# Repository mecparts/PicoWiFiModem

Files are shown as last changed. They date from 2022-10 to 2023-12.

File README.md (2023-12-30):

# Pico WiFi modem

## A Pico W based RS232 \<-\> WiFi modem with Hayes AT style commands and LED indicators

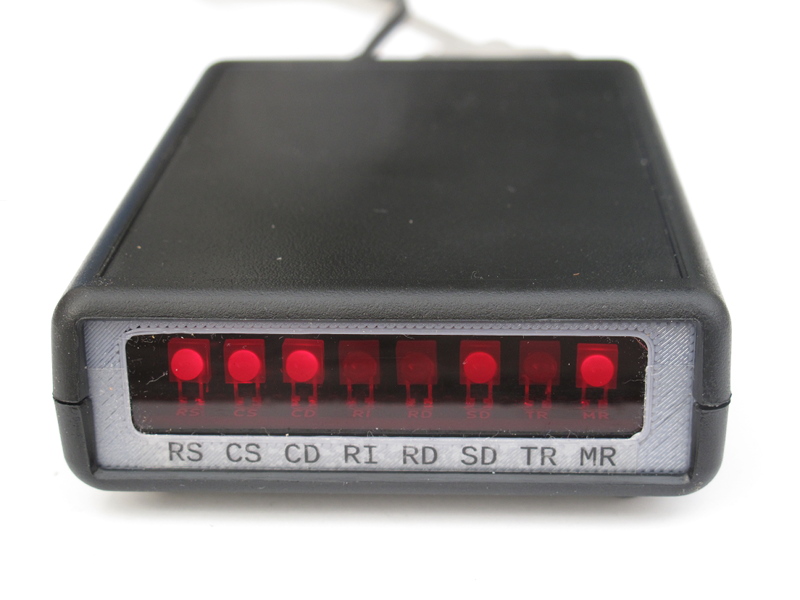
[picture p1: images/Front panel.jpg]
Front Panel
|  |
|:--:|
| The Pico WiFi modem |

This project began as an exercise to learn about the Pico W and lwIP.
Then, as I figured things out, it sort of took on a life of its own...

The code was ported from my 
[Retro WiFi Modem](https://github.com/mecparts/RetroWiFiModem). 
One look at it will betray its Arduino IDE origin! It's definitely not
the most efficient way to do things in the Pico world, but it worked
well enough for my purposes in learning "okay, I know what I want to do
here, but how does the Pico C/C++ SDK do it?"

It likely would have been much faster to install one of the Pico-Arduino
cores. I imagine there would have been far fewer code changes. But I
don't think I would have learned anywhere near as much about the
workings of the Pico W and lwIP as I did by using the Pico SDK.

## The Hardware

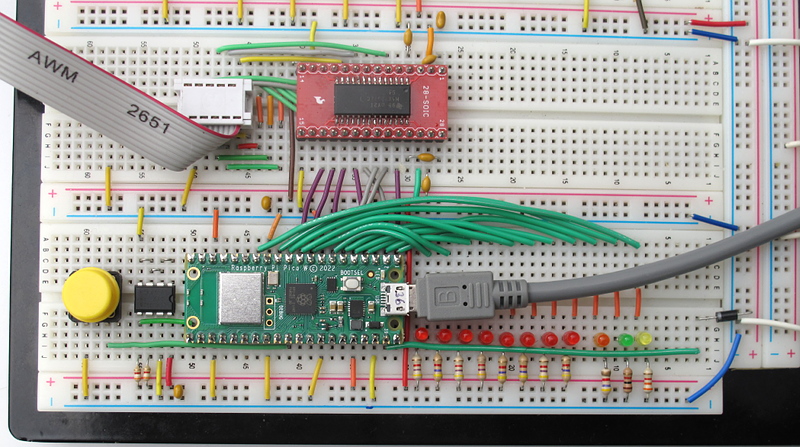
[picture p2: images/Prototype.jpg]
Prototype
|  |
|:--:|
| The prototype |

As with the code, I re-up'd a lot of the original hardware decisions.
But, since this time around it wasn't a pandemic project that I was 
trying to do as much as possible with parts on hand, I used a MAX3237
instead of a MAX3232.

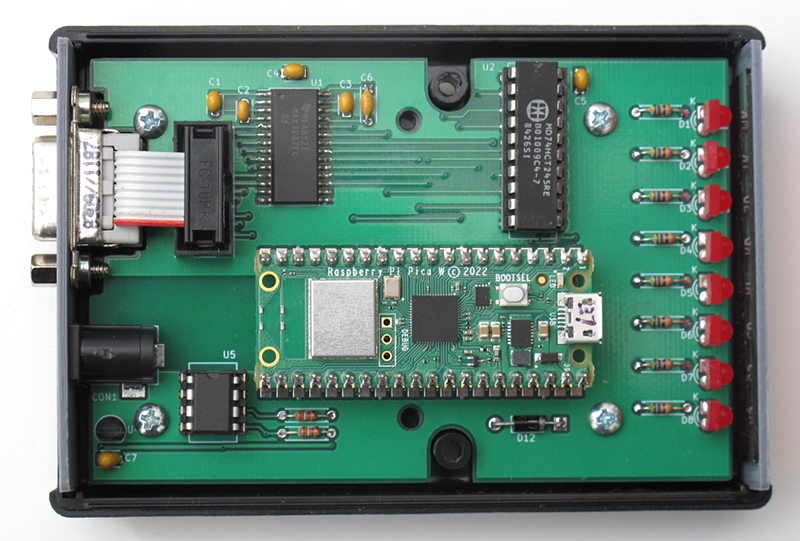
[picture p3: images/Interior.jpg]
Interior
|  |
|:--:|
| The interior |

The modem still uses the classic Hayes style blinking LEDs and a DE-9F
for the RS-232 connector. Everything is displayed: RTS, CTS, DSR, DTR,
DCD, RI, TxD and RxD. And this time, since I used a MAX3237, they're all
brought out to the DE-9F connector. So things like using a change in the
DTR line to go to command mode or end a call are supported (on a system
that brings DTR out to the serial port, of course).

Since the Pico W doesn't have EEPROM on board, I added a small 4K I2C
EEPROM to the mix. I could have used a block of the Pico's flash, but I
wanted to get a feel for I2C on the Pico as well.

The Pico is socketed on this first board due to the lack of OTA
programming. The PCB is set up to allow it to be soldered directly on
the board once I have that figured out.

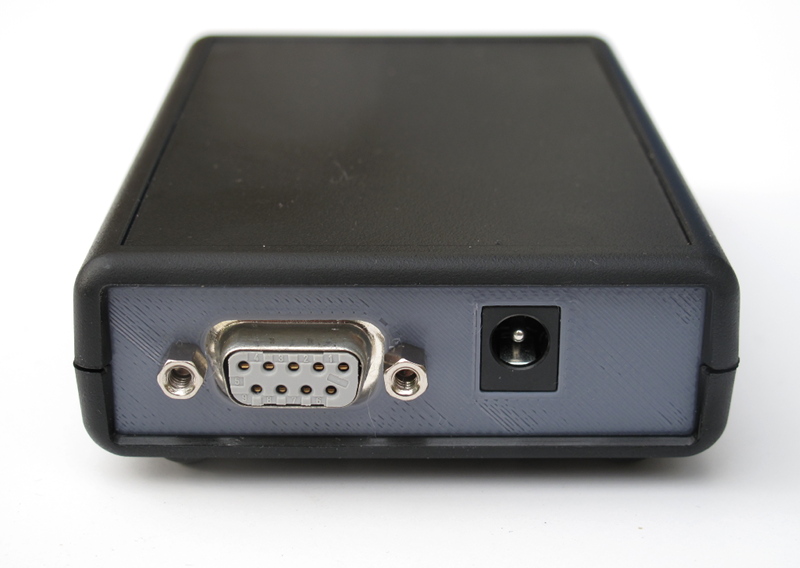
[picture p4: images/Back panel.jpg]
Back Panel
|  |
|:--:|
| The back panel |

The power connector expects a 2.1mm I.D. x 5.5mm O.D. barrel plug,
delivering 5 volts, centre positive.  I used a Tri-Mag L6R06H-050 (5V,
1.2A), [DigiKey part# 364-1251-ND](https://www.digikey.com/product-detail/en/tri-mag-llc/L6R06H-050/364-1251-ND/7682614).
If you plug in a 9V adapter like you'd use for an Arduino, you *will*
let the magic smoke out and have an ex-modem on your hands.

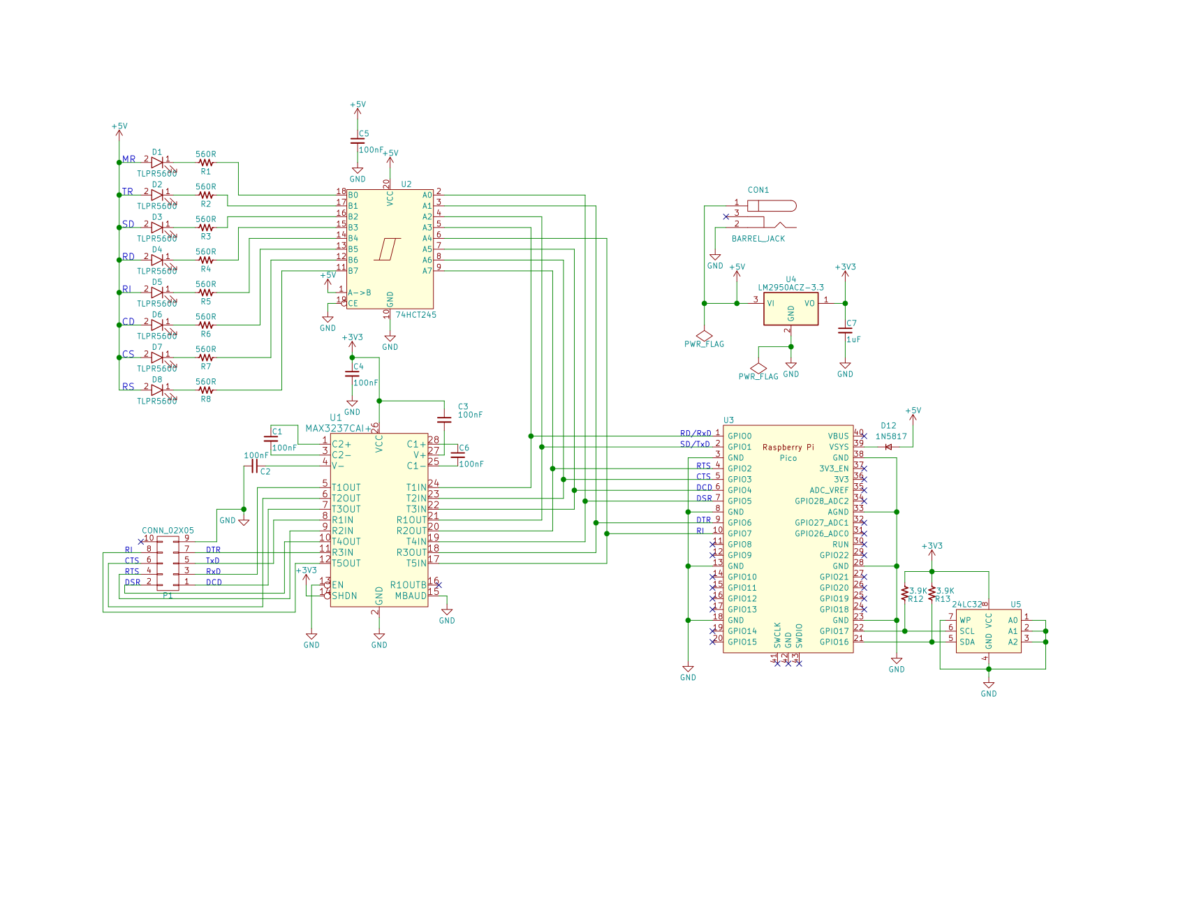
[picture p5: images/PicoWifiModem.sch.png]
Schematic
|  |
|:--:|
| The schematic |

On the off chance that there's someone else out there with a well
stocked parts box and a burning desire to put together their own Pico
WiFi modem, there's a [BOM](kicad/Pico_WiFi_Modem-bom.csv) in the
kicad sub directory. As was true with the original ESP8266 design, if
you actually had to go out and buy all the parts, it really wouldn't be
cost effective.

## The case

I re-used the same case, a Hammond 1593N case (DigiKey part #
[HM963-ND](https://www.digikey.com/en/products/detail/hammond-manufacturing/1593NBK/1090774)
or [HM964-ND](https://www.digikey.com/en/products/detail/hammond-manufacturing/1593NGY/1090775)
depending on whether you like black or grey). STL and OpenSCAD
files are included for the front and back panels. You could use the
proper Hammond red panel for the front (DigiKey part #
[HM965-ND](https://www.digikey.com/en/products/detail/hammond-manufacturing/1593NIR10/1090776)),
*but* they're only available in 10 packs and their price is highway robbery.
I ended up using a slightly smaller red panel (DigiKey part #
[HM889-ND](https://www.digikey.com/en/products/detail/hammond-manufacturing/1593SIR10/409899))
that was ~much~ cheaper (it has recently increased in price by 500%)
and available in single units.

The labels are unbelievably low tech. I print them on a piece of inkjet
transparency film. I then cut that down to size so that it will fit
under the LED opening. Then I attach the trimmed down transparency piece
to a length of matte finish, invisible tape and carefully position it in
place. A bit of careful work with an x-acto knife and you've got
yourself a label that looks like it's part of the panel. If you look
closely at the front panel image you can see the edges of the
transparency film and the tape, but in practice they both essentially
disappear.

## The PCB

The PCB includes cutouts for the two columns that join the case
together, and mounting holes for the 6 standoffs. Also, there's an oddly
shaped cutout in back end to allow a particular IDC DE-9F I had on hand.
It's available from DigiKey (or a very close clone is) but it's fairly
pricey. But there's plenty of room for an ordinary solder cup DE-9F.
You'd most likely want to omit the 10 pin header and just wire the DE-9F
right to the board.

Unlike the original Retro Wifi Modem, I made no attempt to make this
board by hand. Instead, I took advantage of an introductory offer by a
well known PCB house and had PCBs made. 5 boards for under 20 bucks, and
delivered in under a week? Who could say no?

## The Software

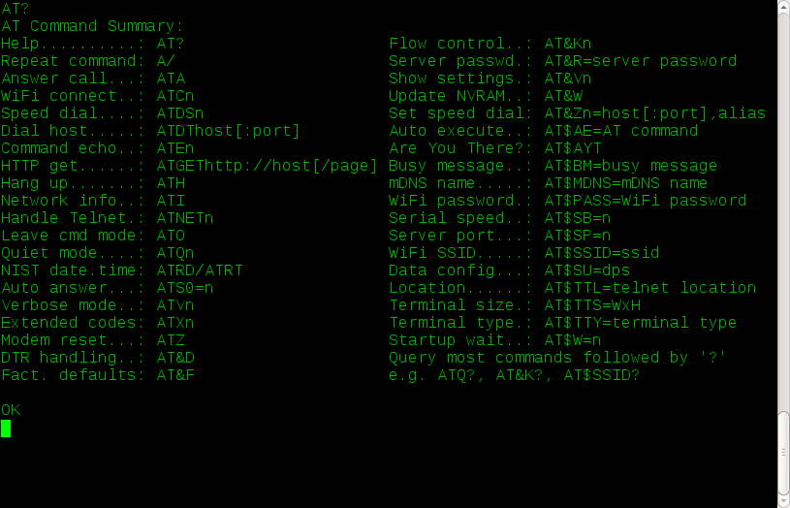
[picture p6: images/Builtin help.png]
Builtin help
|  |
|:--:|
| Modem command list |

The software is naturally quite similar to the original ESP8266 Wifi
modem. There are a few changes (and one fairly major omission):

* DTR signal handling (AT&D)
* Escape sequence character definition (ATS2)
* no OTA reprogramming (yet!)

### First time setup

The default serial configuration is 9600bps, 8 data bits, no parity, 1
stop bit.

Here's the commands you need to set up the modem to automatically
connect to your WiFi network:

1. `AT$SSID=your WiFi network name` to set the WiFi network that the
modem will connect to when it powers up.
2. `AT$PASS=your WiFi network password` to set the password for the
network.
3. `ATC1` to connect to the network.
4. Optional stuff:
   * `AT$SB=speed` to set the default serial speed.
   * `AT$SU=dps` to set the data bits, parity and stop bits.
   * `ATNETn` to select whether or not to use Telnet protocol.
   * `AT&Kn` to use RTS/CTS flow control or not.
   * `AT&Dn` to set up DTR handling.
5. `AT&W` to save the settings.

Once you've done that, the modem will automatically connect to your WiFi
network on power up and will be ready to "dial up" a connection with
ATDT.

### Command Reference

Multiple AT commands can be typed in on a single line. Spaces between
commands are allowed, but not within commands (i.e. AT S0=1 X1 Q0 is
fine; ATS 0=  1 is not). Commands that take a string as an argument
(e.g. AT$SSID=, AT$TTY=) assume that *everything* that follows is a part
of the string, so no commands are allowed after them.

Command | Details
------- | -------
+++     | Online escape code. Once your modem is connected to another device, the only command it recognises is an escape code of a one second pause followed by three typed plus signs and another one second pause, which puts the modem back into local command mode.
A/      | Repeats the last command entered. Do not type AT or press Enter.
AT      | The attention prefix that precedes all command except A/ and +++.
AT?     | Displays a help cheatsheet.
ATA     | Force the modem to answer an incoming connection when the conditions for auto answer have not been satisfied.
ATC?<br>ATC*n* | Query or change the current WiFi connection status. A result of 0 means that the modem is not connected to WiFi, 1 means the modem is connected. The command ATC0 disconnects the modem from a WiFi connection. ATC1 connects the modem to the WiFi.
ATDS*n* | Calls the host specified in speed dial slot *n* (0-9).
ATDT<i>[+=-]host[:port]</i> | Tries to establish a WiFi TCP connection to the specified host name or IP address. If no port number is given, 23 (Telnet) is assumed. You can also use ATDT to dial one of the speed dial slots in one of two ways:<br><br><ul><li>The alias in each speed dial slot is checked to see if it matches the specified hostname.</li><li>A host specified as 7 identical digits dials the slot indicated by the digit. (i.e. 2222222 would speed dial the host in slot 2).</li></ul>Preceding the host name or IP address with a +, = or - character overrides the ATNET setting for the period of the connection.<br><br><ul><li>**+** forces NET2 (fake Telnet)</li><li>**=** forces NET1 (real Telnet)</li><li>**-** forces NET0 (no Telnet)</li></ul>Once the dial attempt has begun, pressing any key before the connection is established will abort the attempt.
ATE?<br>ATE*n* | Command mode echo. Enables or disables the display of your typed commands.<br><br><ul><li>E0 Command mode echo OFF. Your typing will not appear on the screen.</li><li>E1 Command mode echo ON. Your typing will appear on the screen.</li></ul>
ATGET*http&#58;//host[/page]* | Displays the contents of a website page. **https** connections are not supported. Once the contents have been displayed, the connection will automatically terminate.
ATH | Hangs up (ends) the current connection.
ATI | Displays the current network status, including sketch build date, WiFi and call connection state, SSID name, IP address, and bytes transferred.
ATNET?<br>ATNET*n* | Query or change whether telnet protocol is enabled. A result of 0 means that telnet protocol is disabled; 1 is *Real* telnet protocol and 2 is *Fake* telnet protocol. If you are connecting to a telnet server, it may expect the modem to respond to various telnet commands, such as terminal name (set with `AT$TTY`), terminal window size (set with `AT$TTS`) or terminal speed. Telnet protocol should be enabled for these sites, or you will at best see occasional garbage characters on your screen, or at worst the connection may fail.<br><br>The difference between *real* and *fake* telnet protocol is this: with *real* telnet protocol, a carriage return (CR) character being sent from the modem to the telnet server always has a NUL character added after it. The implementation of the telnet protocol used by some BBSes doesn't properly strip out the NUL character. When connecting to such BBSes (Particles! is one), use *fake* telnet.<br><br>When using *real* telnet protocol, when the telnet server sends a CR character followed by a NUL character, only the CR character will be sent to the serial port; the NUL character will be silently stripped out. With *fake* telnet protocol, the NUL will be passed through.
ATO | Return online. Use with the escape code (+++) to toggle between command and online modes.
ATQ?<br>ATQ*n* | Enable or disable the display of result codes. The default is Q0.<br><br><ul><li>Q0 Display result codes.</li><li>Q1 Suppress result codes (quiet).</li></ul>
ATRD<br>ATRT | Displays the current UTC date and time from NIST in the format *YY-MM-DD HH:MM:SS*. A WiFi connection is required and you cannot be connected to another site.
ATS0?<br>ATS0=*n* | Display or set the number of "rings" before answering an incoming connection. Setting `S0=0` means "don't answer".
ATS2?<br>ATS2=*n* | Display or set the ASCII code used in the online escape sequence. The default value is 43 (the + plus character). Setting it to any value between 128 and 255 will disable the online escape function.
ATV?<br>ATV*n* | Display result codes in words or numbers. The default is V1.<br><br><ul><li>V0 Display result codes in numeric form.</li><li>V1 Display result codes in text form.</li></ul>
ATX?<br>ATX*n* | Control the amount of information displayed in the result codes. The default is X1 (extended codes).<br><br><ul><li>X0 Display basic codes (CONNECT, NO CARRIER)</li><li>X1 Display extended codes (CONNECT speed, NO CARRIER (connect time))</li></ul>
ATZ | Resets the modem.
AT&D?<br>AT&D*n* | Display or set the handling of DTR going inactive. The default is &D0 (ignored).<br><br><ul><li>&D0 Ignore</li><li>&D1 Go to command mode</li><li>&D2 End call</li><li>&D3 Reset modem</li></ul>
AT&F | Reset the NVRAM contents and current settings to the sketch defaults. All settings, including SSID name, password and speed dial slots are affected.
AT&K?<br>AT&K*n* | Data flow control. Prevents the modem's buffers for received and transmitted from overflowing.<br><br><ul><li>&K0 Disable data flow control.</li><li>&K1 Use hardware flow control. Requires that your computer and software support Clear to Send (CTS) and Request to Send (RTS) at the RS-232 interface.</li></ul>
AT&R?<br>AT&R=*server pwd* | Query or change the password for incoming connections. If set, the user has 3 chances in 60 seconds to enter the correct password or the modem will end the connection.
AT&V*n* | Display current or stored settings.<br><br><ul><li>&V0 Display current settings.</li><li>&V1 Display stored settings.</li></ul>
AT&W | Save current settings to NVRAM.
AT&Zn?<br>AT&Z*n*=*host[:port],alias* | Store up to 10 numbers in NVRAM, where *n* is the position 0-9 in NVRAM, and *host[:port]* is the host string, and *alias* is the speed dial alias name. The host string may be up to 50 characters long, and the alias string may be up to 16 characters long.<br><br>Example: `AT&Z2=particlesbbs.dyndns.org:6400,particles`<br><br>This number can then be dialed in any of the following ways:<br><br><ul><li>`ATDS2`</li><li>`ATDTparticles`</li><li>`ATDT2222222`</li></ul>
AT$AE?<br>AT$AE=*startup AT cmd* | Query or change the command line to be executed when the modem starts up.
AT$AYT | Sends a Telnet "Are You There?" command if connected to a Telnet remote.
AT$BM?<br>AT$BM=*server busy msg* | Query or change a message to be returned to an incoming connection if the modem is busy (i.e. already has a connection established).
AT$MDNS<br>AT$MDNS=*mDNS name* | Query or change the mDNS network name (defaults to "espmodem"). When a non zero TCP port is defined, you can telnet to that port with **telnet mdnsname.local port**.
AT$PASS?<br>AT$PASS=*WiFi pwd* | Query or change the current WiFi password. The password is case sensitive. Clear the password by issuing the set command with no password. The maximum length of the password is 64 characters.
AT$SB?<br>AT$SB=*n* | Query or change the current baud rate. Valid values for "n" are 110, 300, 450, 600, 710, 1200, 2400, 4800, 9600, 19200, 38400, 57600, 76800 and 115200. Any other value will return an ERROR message. The default baud rate is 1200. The Pico WiFi modem does not automatically detect baud rate like a dial-up modem. The baud rate setting must match that of your terminal to operate properly. It will display garbage in your terminal otherwise.
AT$SP?<br>AT$SP=*n* | TCP server port to listen on. A value of 0 means that the TCP server is disabled, and no incoming connections are allowed.
AT$SSID?<br>AT$SSID=*ssid name* | Query or change the current SSID to the specified name. The given SSID name is case sensitive. Clear the SSID by issuing the set command with no SSID. The maximum length of the SSID name is 32 characters.
AT$SU?<br>AT$SU=*dps* | Query or change the current number of data bits ('d'), parity ('p') and stop bits ('s") of the serial UART. Valid values for 'd' are 5, 6, 7 or 8 bits. Valid values for 'p' are (N)one, (O)dd or (E)ven parity. Valid values for 's' are 1 or 2 bits. The default settings are 8N1. The UART setting must match your terminal to work properly.
AT$TTL?<br>AT$TTL=*telnet location* | Query or change the Telnet location value to be returned when the Telnet server issues a SEND-LOCATION request. The default value is "Computer Room".
AT$TTS?<br>AT$TTS=*WxH* | Query or change the window size (columns x rows) to be returned when the Telnet server issues a NAWS (Negotiate About Window Size) request. The default value is 80x24. For terminals that are smaller than 80x24, setting these values appropriately will enable paging on the help (AT?) and network status (ATI) commands.
AT$TTY?<br>AT$TTY=*terminal type* | Query or change the terminal type to be returned when the Telnet server issues a TERMINAL-TYPE request. The default value is "ansi".
AT$W?<br>AT$W=*n* | Startup wait.<br><br><ul><li>$W=0 Startup with no wait.</li><li>$W=1 Wait for the return key to be pressed at startup.</li></ul>

### Updating the Code

As I'm writing this, I haven't settled on an OTA programming method that
I like. But I will figure something out; taking the modem apart to do a
code update will get old the very first time I have to do it. Plus,
it means that the Pico W can't be soldered down to the PCB, and that'd
be a nice to have as well.

## Status

It's a work in progress at the moment. The lack of OTA programming is
the big "needs to be done" item.

As this is my first Pico project, and the first time I've written lwIP 
stuff (and the first time I've really had to make changes to CMake 
stuff), I've run headlong into all the usual beginner gotchas. And I'm
completely, absolutely sure that I haven't found them all yet.

The code works reasonably well at the moment; it can call out, you can 
call in, Ymodem and Zmodem transfers work, I've figured out why it used
to appear to lock up when I left it alone for 10 minutes (Wifi power
management, if you're wondering)... but I'm under no illusion that there
aren't bugs aplenty yet to be squashed. After all, I found a handful of
problems in the original ESP8266 Retro Wifi modem code while I was
getting the Pico code working, and the ESP code had been pretty much
stable for over two years.

And I think I may have also discovered why every once in a while, the
modem would get behind a few (or many) characters either on receive or
transmit. The 'volatile' qualifier isn't of as much use with variables
modified by two threads as it is with memory mapped I/O or hardware
registers. To make a long story short, '++var' and '--var' aren't
atomic operations; they're read/modify/write. And every once in a great
while the main thread would be updated a buffer length at the same time
the lwIP thread was updating the same buffer length and whackiness
ensued.

For the moment, I've taken the naive approach of surrounding the buffer
length writes with disable/re-enable interrupt calls. I think that will
work reasonably well (though if I ever decided to make use of the second
core, it'll fail because interrupts are only disabled on the calling
core). If not, it'll be time to bone up on mutexes and semaphores and
critical sections.

### Linux, Telnet, Zmodem and downloading binary files

Have you used the modem to 'dial' into a Linux box? And have you done a
`sz binary_file` on the Linux box? And at a completely reproducible
point in the file, has the connection dropped? But other binary files
work just fine? Then read on.

This drove me slightly batty for months on the original Retro modem. I
finally narrowed it down to trying to send blocks of binary data with a
large number of FF bytes. eventually created a test file consisting of
2K of FF and used that to test with. I could download it through the
modem with Xmodem just fine. Ymodem also worked if I kept the block size
down to 128 bytes - but the connection would drop instantly if I tried
sending 1K blocks. Same thing with Zmodem.

In fact, if I just tried `cat binary_file`, the connection would
drop. Which eventually got me thinking. Sitting at the console on my
main Linux box, I telnet'd to the same box and logged in. No WiFi modem
involved anywhere, just a telnet session on the console to the same box.
I then did a `cat binary_file`. The telnet connection dropped, and I
was back in my original session.

It's the Linux telnet daemon. Not the modem at all.

To prove it to myself, I hooked up WiFi modems to two systems on their
serial ports and had one dial into the other. I could send the all FF
binary file back and forth with Zmodem and Ymodem, no trouble at all.

But you really, really need to download that binary file through the
modem from a telnet connection to a Linux box? You're not going to be
able to use Zmodem. Ymodem will work (the sy command defaults to 128
byte blocks), as will Xmodem. But not Zmodem.

Oddly enough, the telnet daemon has no trouble *receiving* the all FF
binary file. Only sending it. Your guess as to why is probably better
than mine.

## References

* [Retro WiFi Modem](https://github.com/mecparts/RetroWiFiModem)
* [WiFi232 - An Internet Hayes Modem for your Retro Computer](http://biosrhythm.com/?page_id=1453)<br>
* [WiFi232's Evil Clone](https://forum.vcfed.org/index.php?threads/wifi232s-evil-clone.1070412/)<br>
* [Jussi Salin's Virtual modem for ESP8266](https://github.com/jsalin/esp8266_modem)<br>
* [Stardot's ESP8266 based virtual modem](https://github.com/stardot/esp8266_modem)<br>
* [Roland Juno's ESP8266 based virtual modem](https://github.com/RolandJuno/esp8266_modem)

## Acknowledgements

* A whole lot of people owe a big vote of thanks to Jussi Salin for
releasing their virtual modem code for the ESP8266 and starting the
ball rolling.
* Paul Rickards for an amazing bit of hardware to draw inspiration from.
* All the Stardot contributors for their work.
* And, of course, Dennis C. Hayes for creating something so simple and
elegant that has stood the test of time.

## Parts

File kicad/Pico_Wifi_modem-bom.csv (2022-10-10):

Reference | Quantity | Value | Price | DigiKey PN
P1 | 1 | CONN_02X05 | 0.41 | ED1543-ND
D1-D8 | 8 | TLPR5600 | 6.4 | TLPR5600-ND
C1-C5 | 5 | 100nF | 1.55 | 399-9859-1-ND
C6 | 1 | 100nF | 0.33 | 399-9843-ND
C7 | 1 | 1uF | 2.54 | 399-3529-ND
CON1 | 1 | BARREL_JACK | 1.09 | 839-54-00166-ND
R1-R8 | 8 | 560R | 1.28 | CF18JT560RCT-ND
U3 | 1 | Pico W | 8.88 | 2648-SC0918CT-ND
U4 | 1 | LM2950ACZ-3.3 | 1.26 | LP2950ACZ-3.3GOS-ND
U1 | 1 | MAX3237ECDWR | 5.37 | 296-36945-1-ND
D12 | 1 | 1N5817 | 0.47 | N5817-TPCT-ND
U5 | 1 | AT24C32E-PUM | 0.98 | AT24C32E-PUM-ND
R12-R13 | 2 | 3.9K | 0.32 | CF18JT3K90CT-ND
U2 | 1 | 74HCT245 | 1.42 | 296-1612-5-ND
 | 1 | Hammond 1593NBK case | 9.26 | HM963-ND
 | 1 | Hammond red panel | 0.88 | HM889-ND
 | 50 | PCB screws | 12.46 | HM1442-ND
 | 1 | 5V wall adapter | 8.92 | 364-1251-ND
 | 1 | DE-9F IDC connector | 19.9 | 5746861-4-ND
 | 2 | D-sub jackscrew | 0.94 | 2057-JS-02-ND
 | 1 | 8 pin DIP socket | 0.44 | 1175-1475-ND
 | 1 | 20 pin DIP socket | 0.67 | 1175-1479-ND
 | 1 | 10 pos IDC socket | 0.69 | 1175-1443-ND
 | 1 | 10 cond ribbon cable | 0.95 | 3M157815-1-ND

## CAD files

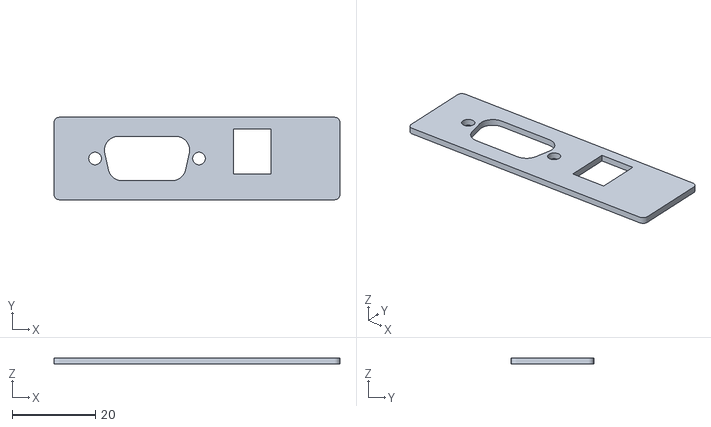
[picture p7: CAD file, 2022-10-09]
case/back_panel.stl
68.8 x 19.8 x 1.50

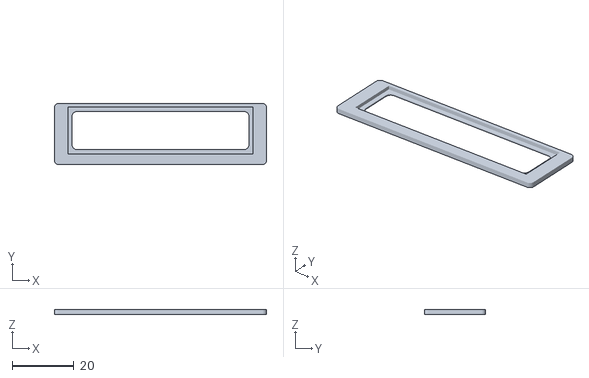
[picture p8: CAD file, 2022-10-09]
case/front_panel.stl
68.8 x 19.8 x 1.50

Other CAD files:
case/back_panel.scad
case/front_panel.scad

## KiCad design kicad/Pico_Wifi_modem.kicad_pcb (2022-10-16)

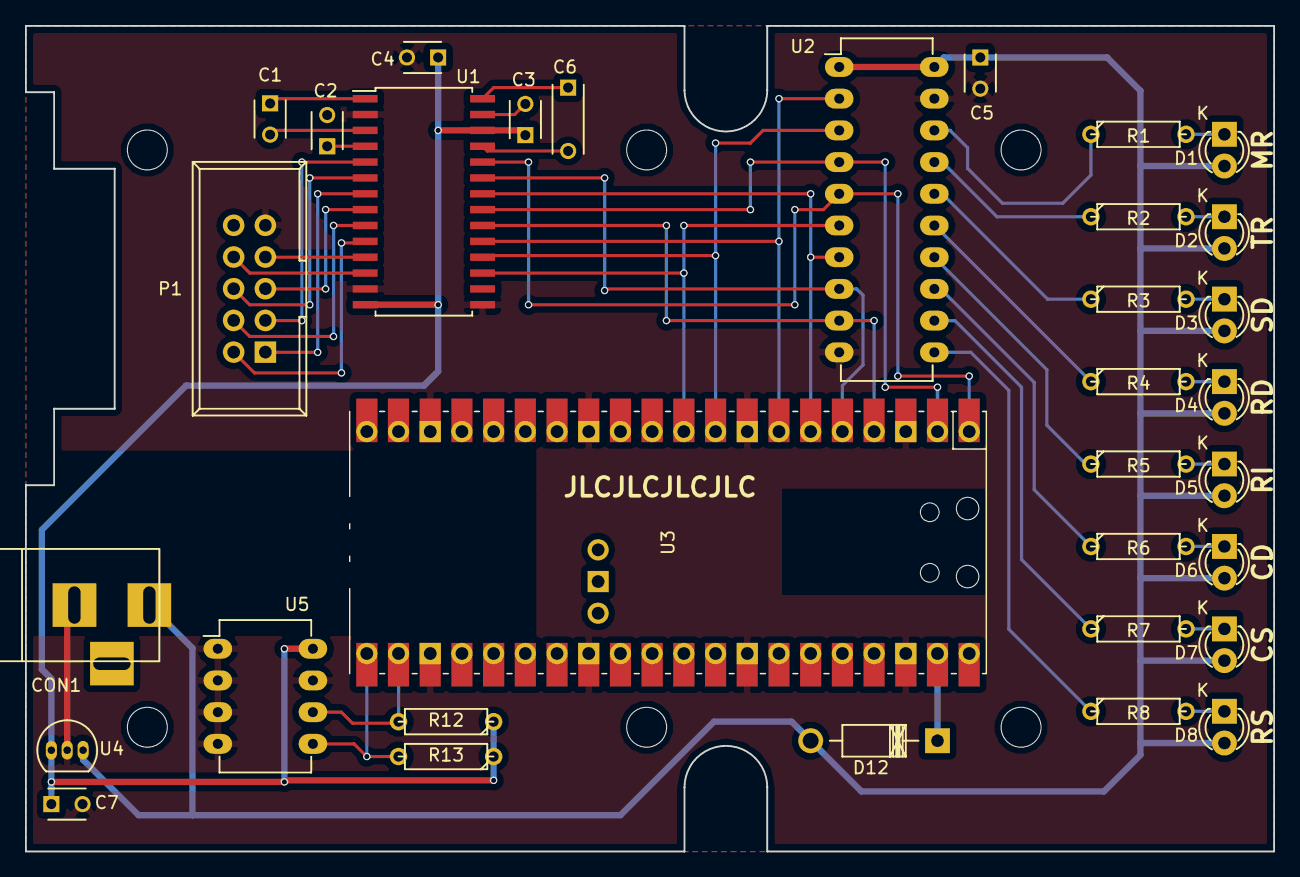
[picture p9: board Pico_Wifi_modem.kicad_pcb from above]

Board: 2 copper layers, 100.0 x 66.1 mm, 33 parts (0 on the bottom side), 44 nets.

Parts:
C1, C2, C3, C4, C5: 100nF; C_Disc_D3_P2.5
C6: 100nF; C_Disc_D3_P5
C7: 1uF; C_Disc_D3_P2.5
CON1: BARREL_JACK
D1, D2, D3, D4, D5, D6, D7, D8: TLPR5600; LED-3MM
D12: 1N5817; Diode_DO-41_SOD81_Horizontal_RM10
P1: CONN_02X05; IDC_Header_Straight_10pins
R1, R2, R3, R4, R5, R6, R7, R8: 560R; R3
R12, R13: 3.9K; R3
U1: MAX3237CAI+; SOIC-28W_7.5x17.9mm_Pitch1.27mm
U2: 74HCT245; DIP-20_W7.62mm_LongPads
U3: Pico; RPi_PicoW
U4: LM2950ACZ-3.3; TO-92_Inline_Narrow_Oval
U5: 24LC32; DIP-8_W7.62mm_LongPads

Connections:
+3V3: C3.1, C4.1, C7.1, R12.1, R13.1, U1.14, U1.26, U4.1, U5.8
+5V: C5.1, CON1.1, D1.2, D2.2, D3.2, D4.2, D5.2, D6.2, D7.2, D8.2, D12.2, U2.1, U2.20, U4.3
GND: C2.2, C4.2, C5.2, C7.2, CON1.2, P1.9, U1.2, U1.13, U1.15, U2.10, U2.19, U3.3, U3.8, U3.13, U3.18, U3.23, U3.28, U3.33, U3.38, U4.2, U5.1, U5.2, U5.3, U5.4, U5.7
unnamed: C1.1, U1.1
unnamed: C1.2, U1.3
unnamed: C2.1, U1.4
unnamed: C3.2, U1.27
unnamed: C6.1, U1.28
unnamed: C6.2, U1.25
unnamed: D1.1, R1.2
unnamed: D2.1, R2.2
unnamed: D3.1, R3.2
unnamed: D4.1, R4.2
unnamed: D5.1, R5.2
unnamed: D6.1, R6.2
unnamed: D7.1, R7.2
unnamed: D8.1, R8.2
unnamed: D12.1, U3.39
unnamed: P1.1, U1.7
unnamed: P1.2, U1.10
unnamed: P1.3, U1.5
unnamed: P1.4, U1.9
unnamed: P1.5, U1.8
unnamed: P1.6, U1.6
unnamed: P1.7, U1.11
unnamed: P1.8, U1.12
unnamed: R1.1, U2.18
unnamed: R2.1, U2.17
unnamed: R3.1, U2.16
unnamed: R4.1, U2.15
unnamed: R5.1, U2.14
unnamed: R6.1, U2.13
unnamed: R7.1, U2.12
unnamed: R8.1, U2.11
unnamed: R12.2, U3.22, U5.6
unnamed: R13.2, U3.21, U5.5
unnamed: U1.17, U2.6, U3.10
unnamed: U1.18, U2.3, U3.9
unnamed: U1.19, U2.2, U3.7
unnamed: U1.20, U2.9, U3.4
unnamed: U1.21, U2.4, U3.2
unnamed: U1.22, U2.7, U3.6
unnamed: U1.23, U2.8, U3.5
unnamed: U1.24, U2.5, U3.1

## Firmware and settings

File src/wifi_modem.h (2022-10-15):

#ifndef _MODEM_H
   #define _MODEM_H

   #define DEBUG                 0
   #define DEFAULT_SPEED         9600

   #define RING_INTERVAL         1500
   #define MAX_CMD_LEN           256
   #define TX_BUF_SIZE           256
   #define ESC_CHAR              '+'
   #define ESC_COUNT             3
   #define GUARD_TIME            1000
   #define MAGIC_NUMBER          0x5678
   #define MAX_SSID_LEN          32
   #define MAX_WIFI_PWD_LEN      64
   #define DEFAULT_LISTEN_PORT   6400
   #define TELNET_PORT           23
   #define HTTP_PORT             80
   #define SPEED_DIAL_SLOTS      10
   #define MAGIC_ANSWER_RINGS    3
   #define MAX_ALIAS_LEN         16
   #define MAX_SPEED_DIAL_LEN    50
   #define MAGIC_SPEED_LEN       7
   #define MAX_MDNSNAME_LEN      80
   #define MAX_BUSYMSG_LEN       80
   #define MAX_PWD_LEN           80
   #define PASSWORD_TIME         60000
   #define PASSWORD_TRIES        3
   #define MAX_AUTOEXEC_LEN      80
   #define MAX_TERMINAL_LEN      80
   #define MAX_LOCATION_LEN      80

   #define NUL  '\x00'
   #define CTLC '\x03'
   #define BS   '\x08'
   #define LF   '\x0A'
   #define CR   '\x0D'
   #define DEL  '\x7F'

   #define NO_TELNET   ((uint8_t)0)
   #define REAL_TELNET ((uint8_t)1)
   #define FAKE_TELNET ((uint8_t)2)

   // Telnet codes
   #define VLSUP     ((uint8_t)0)
   #define VLREQ     ((uint8_t)1)
   #define LOC       ((uint8_t)23)
   #define TTYPE     ((uint8_t)24)
   #define NAWS      ((uint8_t)31)
   #define TSPEED    ((uint8_t)32)
   #define LFLOW     ((uint8_t)33)
   #define LINEMODE  ((uint8_t)34)
   #define XDISPLOC  ((uint8_t)35)
   #define NEW_ENVIRON ((uint8_t)39)
   #define BINARY    ((uint8_t)0)
   #define ECHO      ((uint8_t)1)
   #define SUP_GA    ((uint8_t)3)
   #define SE        ((uint8_t)240)
   #define DM        ((uint8_t)242)
   #define BRK       ((uint8_t)243)
   #define AYT       ((uint8_t)246)
   #define SB        ((uint8_t)250)
   #define WILL      ((uint8_t)251)
   #define WONT      ((uint8_t)252)
   #define DO        ((uint8_t)253)
   #define DONT      ((uint8_t)254)
   #define IAC       ((uint8_t)255)

   #define NIST_HOST "time.nist.gov"
   #define NIST_PORT 13

   #define ACTIVE LOW           // RS232 control signals are active low

   #define RTS  2           // (GPIO02) input
   #define CTS  3           // (GPIO03) output
   #define DCD  4           // (GPIO04) output
   #define DSR  5           // (GPIO05) output
   #define DTR  6           // (GPIO06) input
   #define RI   7           // (GPIO07) output
   
   #define OUTPUT true
   #define INPUT  false
   #define HIGH   true
   #define LOW    false

   // I2C EEPROM definitions
   #define I2C_ADDR  0x50
   #define I2C_SDA   16
   #define I2C_SCL   17
   #define I2C_BAUD  100000
   
   #define TCP_CLIENT_RX_BUF_SIZE 20000
   #define TCP_CLIENT_TX_BUF_SIZE 1100
   
#ifndef NDEBUG
   #define POLL_STATE_LED 8
   #define RXBUFF_OVFL 9
   #define TXBUFF_OVFL 10
#endif

#endif

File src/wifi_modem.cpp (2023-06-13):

//
//   Pico WiFi modem: a Pico W based RS232<->WiFi modem
//   with Hayes style AT commands and blinking LEDs.
//
//   A "let's learn about the Pico W and lwIP" project. It
//   betrays its ESP8266 + Arduino IDE roots in its
//   structure; certainly no one would start a Pico
//   project from scratch and write it this way!
//
//   Originally based on
//   Original Source Copyright (C) 2016 Jussi Salin <salinjus@gmail.com>
//   Additions (C) 2018 Daniel Jameson, Stardot Contributors
//   Additions (C) 2018 Paul Rickards <rickards@gmail.com>
//   Additions 2020-2022 Wayne Hortensius
//
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
#include <string.h>
#include <time.h>
#include <malloc.h>

#include "pico/stdlib.h"
#include "pico/cyw43_arch.h"
#include "hardware/watchdog.h"
#include "hardware/i2c.h"
#include "hardware/sync.h"

#include "lwip/pbuf.h"
#include "lwip/tcp.h"
#include "lwip/dns.h"


#include "wifi_modem.h"
#include "globals.h"
#include "eeprom.h"
#include "tcp_support.h"
#include "support.h"
#include "at_basic.h"
#include "at_extended.h"
#include "at_proprietary.h"

// =============================================================
void setup(void) {
   bool ok = true;

   stdio_init_all();

   gpio_init(DTR);
   gpio_set_dir(DTR, INPUT);

   gpio_init(RI);
   gpio_set_dir(RI, OUTPUT);
   gpio_put(RI, !ACTIVE);           // not ringing

   gpio_init(DCD);
   gpio_set_dir(DCD, OUTPUT);
   gpio_put(DCD, !ACTIVE);          // not connected

   gpio_init(DSR);
   gpio_set_dir(DSR, OUTPUT);
   gpio_put(DSR, !ACTIVE);          // modem is not ready
#ifndef NDEBUG
   gpio_init(POLL_STATE_LED);
   gpio_set_dir(POLL_STATE_LED, OUTPUT);
   gpio_put(POLL_STATE_LED, LOW);
   
   gpio_init(RXBUFF_OVFL);
   gpio_set_dir(RXBUFF_OVFL, OUTPUT);
   gpio_put(RXBUFF_OVFL, LOW);

   gpio_init(TXBUFF_OVFL);
   gpio_set_dir(TXBUFF_OVFL, OUTPUT);
   gpio_put(TXBUFF_OVFL, LOW);
#endif
   initEEPROM();
   readSettings(&settings);

   if( settings.magicNumber != MAGIC_NUMBER ) {
      // no valid data in EEPROM/NVRAM, populate with defaults
      factoryDefaults(NULL);
   }
   sessionTelnetType = settings.telnet;

   uart_set_baudrate(uart0, settings.serialSpeed);
   uart_set_format(uart0, settings.dataBits, settings.stopBits, settings.parity);
   uart_set_translate_crlf(uart0, false);
   setHardwareFlow(settings.rtsCts);

   // enable interrupt when DTR goes inactive if we're not ignoring it
   gpio_set_irq_enabled_with_callback(DTR, GPIO_IRQ_EDGE_RISE, settings.dtrHandling != DTR_IGNORE, dtrIrq );

   if( settings.startupWait ) {
      while( true ) {            // wait for a CR
         if( uart_is_readable(uart0) ) {
            if( uart_getc(uart0) == CR ) {
               break;
            }
         }
      }
   }

   cyw43_arch_init();
   cyw43_arch_enable_sta_mode();
   // disable Wifi power management
   // if this is not done, after 5-10 minutes the Pico W does not
   // respond to incoming packets and can only be awoken by the
   // arrival of serial data
   cyw43_wifi_pm(&cyw43_state, CYW43_DEFAULT_PM & ~0xf);
   if( settings.ssid[0] ) {
      for( int i = 0; i < 4; ++i ) {
         cyw43_arch_wifi_connect_timeout_ms(settings.ssid, settings.wifiPassword, CYW43_AUTH_WPA2_AES_PSK, 10000);
         if( cyw43_tcpip_link_status(&cyw43_state, CYW43_ITF_STA) == CYW43_LINK_UP ) {
            break;
         }
      }
   }

   if( settings.listenPort ) {
      tcpServerStart(&tcpServer, settings.listenPort);
   }

#if OTA_UPDATE_ENABLED
   if( settings.ssid[0] && cyw43_tcpip_link_status(&cyw43_state, CYW43_ITF_STA) == CYW43_LINK_UP ) {
      setupOTAupdates();
   }
#endif

   if( cyw43_tcpip_link_status(&cyw43_state, CYW43_ITF_STA) == CYW43_LINK_UP || !settings.ssid[0] ) {
      if( cyw43_tcpip_link_status(&cyw43_state, CYW43_ITF_STA) == CYW43_LINK_UP ) {
         gpio_put(DSR, ACTIVE);  // modem is finally ready or SSID not configured
         dns_init();
      }
      if( settings.autoExecute[0] ) {
         strncpy(atCmd, settings.autoExecute, MAX_CMD_LEN);
         atCmd[MAX_CMD_LEN] = NUL;
         if( settings.echo ) {
            printf("%s\r\n", atCmd);
         }
         doAtCmds(atCmd);                  // auto execute command
      } else {
         sendResult(R_OK);
      }
   } else {
      sendResult(R_ERROR);           // SSID configured, but not connected
   }
}

// =============================================================
void loop(void) {

   checkForIncomingCall();

   if( settings.dtrHandling == DTR_RESET && checkDtrIrq() ) {
      resetToNvram(NULL);
   }

   switch( state ) {

      case CMD_NOT_IN_CALL:
#if OTA_UPDATE_ENABLED
         if( cyw43_tcpip_link_status(&cyw43_state, CYW43_ITF_STA) == CYW43_LINK_UP ) {
            ArduinoOTA.handle();
         }
#endif
         inAtCommandMode();
         break;

      case CMD_IN_CALL:
         inAtCommandMode();
         if( state == CMD_IN_CALL && !tcpIsConnected(tcpClient) ) {
            endCall();                    // hang up if not in a call
         }
         break;

      case PASSWORD:
         inPasswordMode();
         break;

      case ONLINE:
         if( uart_is_readable(uart0) ) {       // data from RS-232 to Wifi
            sendSerialData();
         }

         while( tcpBytesAvailable(tcpClient) && !uart_is_readable(uart0) ) { 
            // data from WiFi to RS-232
            int c = receiveTcpData();
            if( c != -1 ) {
               uart_putc_raw(uart0, (char)c);
            }
         }

         if( escCount == ESC_COUNT && millis() > guardTime ) {
            state = CMD_IN_CALL;          // +++ detected, back to command mode
            sendResult(R_OK);
            escCount = 0;
         }

         if( settings.dtrHandling != DTR_IGNORE && checkDtrIrq() ) {
            switch( settings.dtrHandling ) {
               
               case DTR_GOTO_COMMAND:
                  state = CMD_IN_CALL;
                  sendResult(R_OK);
                  escCount = 0;
                  break;
                  
               case DTR_END_CALL:
                  endCall();
                  break;
                  
               case DTR_RESET:
                  resetToNvram(NULL);
                  break;
            }
         }

         if( !tcpIsConnected(tcpClient) ) {   // no client?
            endCall();                        // then hang up
         }
         break;
   }
}

// =============================================================
void doAtCmds(char *atCmd) {
   size_t len;

   trim(atCmd);               // get rid of leading and trailing spaces
   if( atCmd[0] ) {
      // is it an AT command?
      if( strncasecmp(atCmd, "AT", 2) ) {
         sendResult(R_ERROR); // nope, time to die
      } else {
         // save command for possible future A/
         strncpy(lastCmd, atCmd, MAX_CMD_LEN);
         lastCmd[MAX_CMD_LEN] = NUL;
         atCmd += 2;          // skip over AT prefix
         len = strlen(atCmd);

         if( !atCmd[0] ) {
            // plain old AT
            sendResult(R_OK);
         } else {
            trim(atCmd);
            while( atCmd[0] ) {
               if( !strncasecmp(atCmd, "?", 1)  ) { // help message
                  // help
                  atCmd = showHelp(atCmd + 1);
               } else if( !strncasecmp(atCmd, "$AYT", 4) ) {
                  // send Telnet "Are You There?"
                  atCmd = doAreYouThere(atCmd + 4);
               } else if( !strncasecmp(atCmd, "$SB", 3) ) {
                  // query/set serial speed
                  atCmd = doSpeedChange(atCmd + 3);
               } else if( !strncasecmp(atCmd, "$SU", 3) ) {
                  // query/set serial data configuration
                  atCmd = doDataConfig(atCmd + 3);
               } else if( !strncasecmp(atCmd, "$SSID", 5) ) {
                  // query/set WiFi SSID
                  atCmd = doSSID(atCmd + 5);
               } else if( !strncasecmp(atCmd, "$PASS", 5) ) {
                  // query/set WiFi password
                  atCmd = doWiFiPassword(atCmd + 5);
               } else if( !strncasecmp(atCmd, "C", 1) ) {
                  // connect/disconnect to WiFi
                  atCmd = wifiConnection(atCmd + 1);
               } else if( !strncasecmp(atCmd, "D", 1) && len > 2 && strchr("TPI", toupper(atCmd[1])) ) {
                  // dial a number
                  atCmd = dialNumber(atCmd + 2);
               } else if( !strncasecmp(atCmd, "DS", 2) && len == 3 ) {
                  // speed dial a number
                  atCmd = speedDialNumber(atCmd + 2);
               } else if( !strncasecmp(atCmd, "H0", 2) ) {
                  // hang up call
                  atCmd = hangup(atCmd + 2);
               } else if( !strncasecmp(atCmd, "H", 1) && !isdigit(atCmd[1]) ) {
                  // hang up call
                  atCmd = hangup(atCmd + 1);
               } else if( !strncasecmp(atCmd, "&Z", 2) && isdigit(atCmd[2]) ) {
                  // speed dial query or set
                  atCmd = doSpeedDialSlot(atCmd + 2);
               } else if( !strncasecmp(atCmd, "O", 1) ) {
                  // go online
                  atCmd = goOnline(atCmd + 1);
               } else if( !strncasecmp(atCmd, "GET", 3) ) {
                  // get a web page (http only, no https)
                  atCmd = httpGet(atCmd + 3);
               } else if( settings.listenPort && !strncasecmp(atCmd, "A", 1) && serverHasClient(&tcpServer) ) {
                  // manually answer incoming connection
                  atCmd = answerCall(atCmd + 1);
               } else if( !strncasecmp(atCmd, "S0", 2) ) {
                  // query/set auto answer
                  atCmd = doAutoAnswerConfig(atCmd + 2);
               } else if( !strncasecmp(atCmd, "S2", 2) ) {
                  // query/set escape character
                  atCmd = doEscapeCharConfig(atCmd + 2);
               } else if( !strncasecmp(atCmd, "$SP", 3) ) {
                  // query set inbound TCP port
                  atCmd = doServerPort(atCmd + 3);
               } else if( !strncasecmp(atCmd, "$BM", 3) ) {
                  // query/set busy message
                  atCmd = doBusyMessage(atCmd + 3);
               } else if( !strncasecmp(atCmd, "&R", 2) ) {
                  // query/set require password
                  atCmd = doServerPassword(atCmd + 2);
               } else if( !strncasecmp(atCmd, "I", 1) ) {
                  // show network information
                  atCmd = showNetworkInfo(atCmd + 1);
               } else if( !strncasecmp(atCmd, "Z", 1) ) {
                  // reset to NVRAM
                  atCmd = resetToNvram(atCmd + 1);
               } else if( !strncasecmp(atCmd, "&V", 2) ) {
                  // display current and stored settings
                  atCmd = displayAllSettings(atCmd + 2);
               } else if( !strncasecmp(atCmd, "&W", 2) ) {
                  // write settings to EEPROM
                  atCmd = updateNvram(atCmd + 2);
               } else if( !strncasecmp(atCmd, "&D", 2) ) {
                  // DTR transition handling
                  atCmd = doDtrHandling(atCmd + 2);
               } else if( !strncasecmp(atCmd, "&F", 2) ) {
                  // factory defaults
                  atCmd = factoryDefaults(atCmd);
               } else if( !strncasecmp(atCmd, "E", 1) ) {
                  // query/set command mode echo
                  atCmd = doEcho(atCmd + 1);
               } else if( !strncasecmp(atCmd, "Q", 1) ) {
                  // query/set quiet mode
                  atCmd = doQuiet(atCmd + 1);
               } else if( !strncasecmp(atCmd, "RD", 2)
                       || !strncasecmp(atCmd, "RT", 2) ) {
                  // read time and date
                  atCmd = doDateTime(atCmd + 2);
               } else if( !strncasecmp(atCmd, "V", 1) ) {
                  // query/set verbose mode
                  atCmd = doVerbose(atCmd + 1);
               } else if( !strncasecmp(atCmd, "X", 1) ) {
                  // query/set extended result codes
                  atCmd = doExtended(atCmd + 1);
               } else if( !strncasecmp(atCmd, "$W", 2) ) {
                  // query/set startup wait
                  atCmd = doStartupWait(atCmd + 2);
               } else if( !strncasecmp(atCmd, "NET", 3) ) {
                  // query/set telnet mode
                  atCmd = doTelnetMode(atCmd + 3);
               } else if( !strncasecmp(atCmd, "$AE", 3) ) {
                  // do auto execute commands
                  atCmd = doAutoExecute(atCmd + 3);
               } else if( !strncasecmp(atCmd, "$TTY", 4) ) {
                  // do telnet terminal type
                  atCmd = doTerminalType(atCmd + 4);
               } else if( !strncasecmp(atCmd, "$TTL", 4) ) {
                  // do telnet location
                  atCmd = doLocation(atCmd + 4);
               } else if( !strncasecmp(atCmd, "$TTS", 4) ) {
                  // do telnet location
                  atCmd = doWindowSize(atCmd + 4);
               } else if( !strncasecmp(atCmd, "&K", 2) ) {
                  // do RTS/CTS flow control
                  atCmd = doFlowControl(atCmd + 2);
               } else if( !strncasecmp(atCmd, "$MDNS", 5) ) {
                  // handle mDNS name
                  atCmd = doMdnsName(atCmd + 5);
               } else {
                  // unrecognized command
                  sendResult(R_ERROR);
               }
               trim(atCmd);
            }
         }
      }
   }
}

int main(void) {
   setup();
   while( true ) {
      loop();
   }
   return 0;
}

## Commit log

2022-10-02 Added Hayes-style S2 (escape sequence character) support. Allow changing (or even disabling) the character used to go from online to online command mode. Disabling it saves problems when both ends of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
    [at_basic.h, support.h, wifi_modem.cpp]
2022-10-02 TCP pacing and ending endless loop of Telnet commands 1. I have code that gets the remote end to (eventually) pausing sending packets. I'd tried something similar early on but didn't realize that it 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
    [at_basic.h, support.h, wifi_modem.h]
2022-10-09 Added front & back panel files
    [back_panel.scad, back_panel.stl, front_panel.scad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]
2022-10-09 Added schematic and PCB files
    [Pico_Wifi_modem-B.Cu.gbl, Pico_Wifi_modem-B.Mask.gbs, Pico_Wifi_modem-B.Paste.gbp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]
2022-10-10 Added updated bill of materials
    [Pico_Wifi_modem-bom.csv]
2022-10-11 DTR handling, more volatiles, tighten up online escape timing 1. Once I got a serial bracket for one of my Linux boxes and set the modem up as a dialin port, I discovered that I needed to reset the '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
    [at_basic.h, support.h, wifi_modem.cpp]
2022-10-12 Tracked down how head and tail ended up out of sync in txBuff If tcpSend got called by the lwIP thread when it's been called by the main thread (from tcpWriteBuf), the queue was catfu'd. Moving cyw43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
    [at_basic.h, support.h, wifi_modem.cpp]
2022-10-12 Turn off Wifi power saving mode fix to prevent Wifi "going away". 5-10 minutes of no data being sent to Wifi resulted in an apparently hung system. The Pico W didn't even respond to pings. Though as 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
    [support.h, wifi_modem.cpp]
2022-10-13 Retransmit data later if tcp_write fails Only update txBuff head and len if tcp_write succeeds, allowing data to be re-tried later on, either from tcpSent or tcpPoll.
    [at_basic.h, support.h]
2022-10-13 Add schematic image
2022-10-15 First stab at a solution for buffer ptrs getting out of sync Long story short: adding 'volatile' does little for variables being written to by two threads, like the buffer lengths. I couldn't figure 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
    [at_basic.h, support.h, wifi_modem.cpp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]
2022-10-16 Had the SD & RD LEDs reversed: fixed It'd be easy enough to criss cross R3 and R4 and use the original PCB, but it was easy enough to fix as well.
    [Pico_Wifi_modem-B.Cu.gbl, Pico_Wifi_modem-B.Mask.gbs, Pico_Wifi_modem-B.Paste.gbp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]
2022-10-17 Fixed a minor bug in ATH that's been there since the beginning
    [at_basic.h, wifi_modem.cpp]
2023-06-10 Added a "how to use it" bit in the readme for the label PDF file and noted the recent price hike on the red LED panel.
2023-06-13 Getting around to commit'ing some HW flow tweaks and other minutae
2023-12-30 Fixed a spelling mistake at added in the missing ATS2 doc.
    [Pico_Wifi_modem.sch]

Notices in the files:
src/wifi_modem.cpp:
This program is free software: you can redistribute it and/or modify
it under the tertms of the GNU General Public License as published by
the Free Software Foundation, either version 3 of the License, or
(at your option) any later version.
